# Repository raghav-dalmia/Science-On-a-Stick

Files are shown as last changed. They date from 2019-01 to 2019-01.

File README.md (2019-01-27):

# Science-On-a-Stick
Science on a Stick, as the name suggests, it is an experimental setup based on Python and Arduino, was developed to verify various laws of Physics such as Lenz's Law, Faraday's Law and Laws of Motion.

We have provided schematics of circuits and code for this project.

# Installation

## To install Arduino IDE
Click [here](https://www.arduino.cc/en/Main/Software) to download Arduino IDE.

## To setup up Python Environment
To download Python IDE, click [here](https://www.python.org/downloads/release/python-2715/).

**Note:-** t would be preferable to download the latest version Python2.7.

### To set up environment variables
----
**Windows 10 and Windows 8**

1. In Search, search for and then select: System (Control Panel)

2. Click the Advanced system settings link.

3. Click Environment Variables. In the section System Variables, find the PATH environment variable and select it. Click Edit. If the PATH environment variable does not exist, click New.

4. In the Edit System Variable (or New System Variable) window, specify the value (location of the folder where python installed) of the PATH environment variable. Click OK. Close all remaining windows by clicking OK.

5. Open Command prompt window, and run following command:
    
       python --version
       pip --version
       
 If pip is not installed in your laptop, refer [this.](https://github.com/pypa/get-pip)
## Install dependencies of python code
open Command prompt or terminal and run this command
    
    pip install pyserial
    pip install matplotlib
    pip install numpy

## To Install Eagle
Download Eagle (PCB design software) from this [link.](https://www.autodesk.in/products/eagle/free-download?referrer=%2Fproducts%2Feagle%2Ffree-download)

Open the given board layouts and fabricate them. The schematic folder has three schematics and their board layouts. 

**Images of Fabricated Board and coil**
---------------------------------------
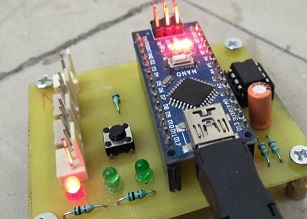
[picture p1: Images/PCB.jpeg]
main_board


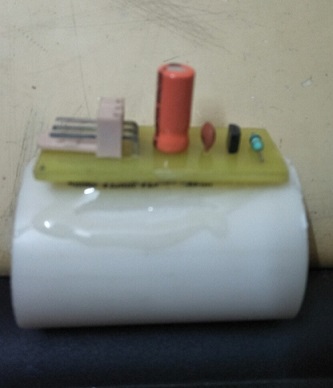
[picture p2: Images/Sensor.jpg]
sensor


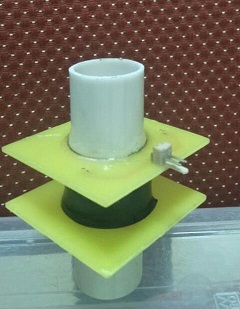
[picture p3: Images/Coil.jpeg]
coil


**!! More than 1000 turns (36 gauge copper wire) of coil winding can destroy the circuit**

# Usage

## Law's of MOtion

Set the experimental tube as shown in [picture.](https://github.com/raghav-dalmia/Science-On-a-Stick/blob/master/Images/Law's%20of%20Motion%20Setup.jpeg)

1. open Arduino IDE and upload `Laws_of_Motion` code.

2. For law's motion open the serial monitor and enter values asked by monitor.

**Output**
----------
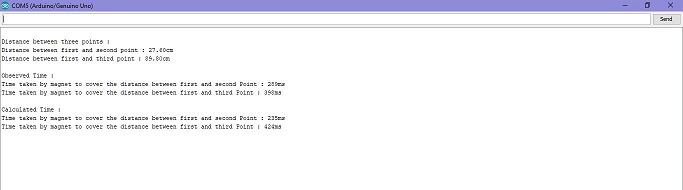
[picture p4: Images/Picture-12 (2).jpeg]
output


## Lenz's Law

Set the experimental setup as shown in [picture.](https://github.com/raghav-dalmia/Science-On-a-Stick/blob/master/Images/Lenz's%20Law%20Setup.jpeg)

1. Open Arduino IDE and upload `Lenz_s_Law_Arduino` code.
2. Open python code and change com port value(in Windows its `com5`, in Linux its `/dev/ttyUSB0`)
    
       arduinoData=serial.Serial('com5',115200)
3. Open Command prompt or terminal and  change current working directory to directory of this python code using
         
       cd <complete-path>
4. Run python code by the following command

       python "Lenz's_Law_Python.py"
   
**Output**
----------
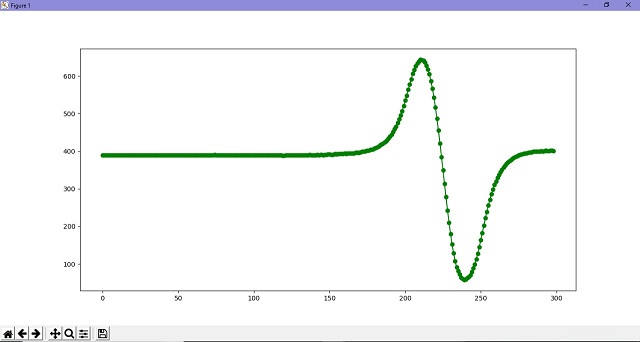
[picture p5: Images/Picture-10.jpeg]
output1


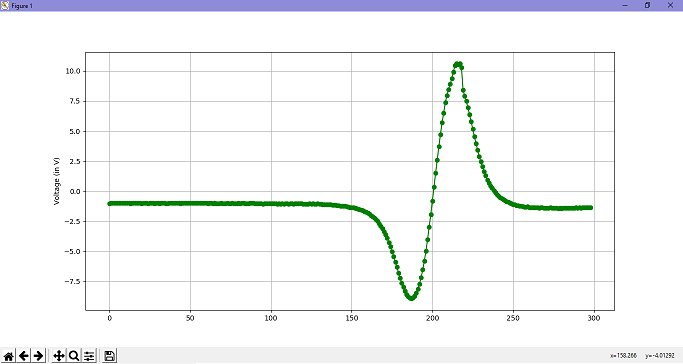
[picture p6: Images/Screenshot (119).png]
output2

       
# Credits
This experimental setup is developed under the guidance of Prof. D.V. Gadre, Director CEDT, NSUT.

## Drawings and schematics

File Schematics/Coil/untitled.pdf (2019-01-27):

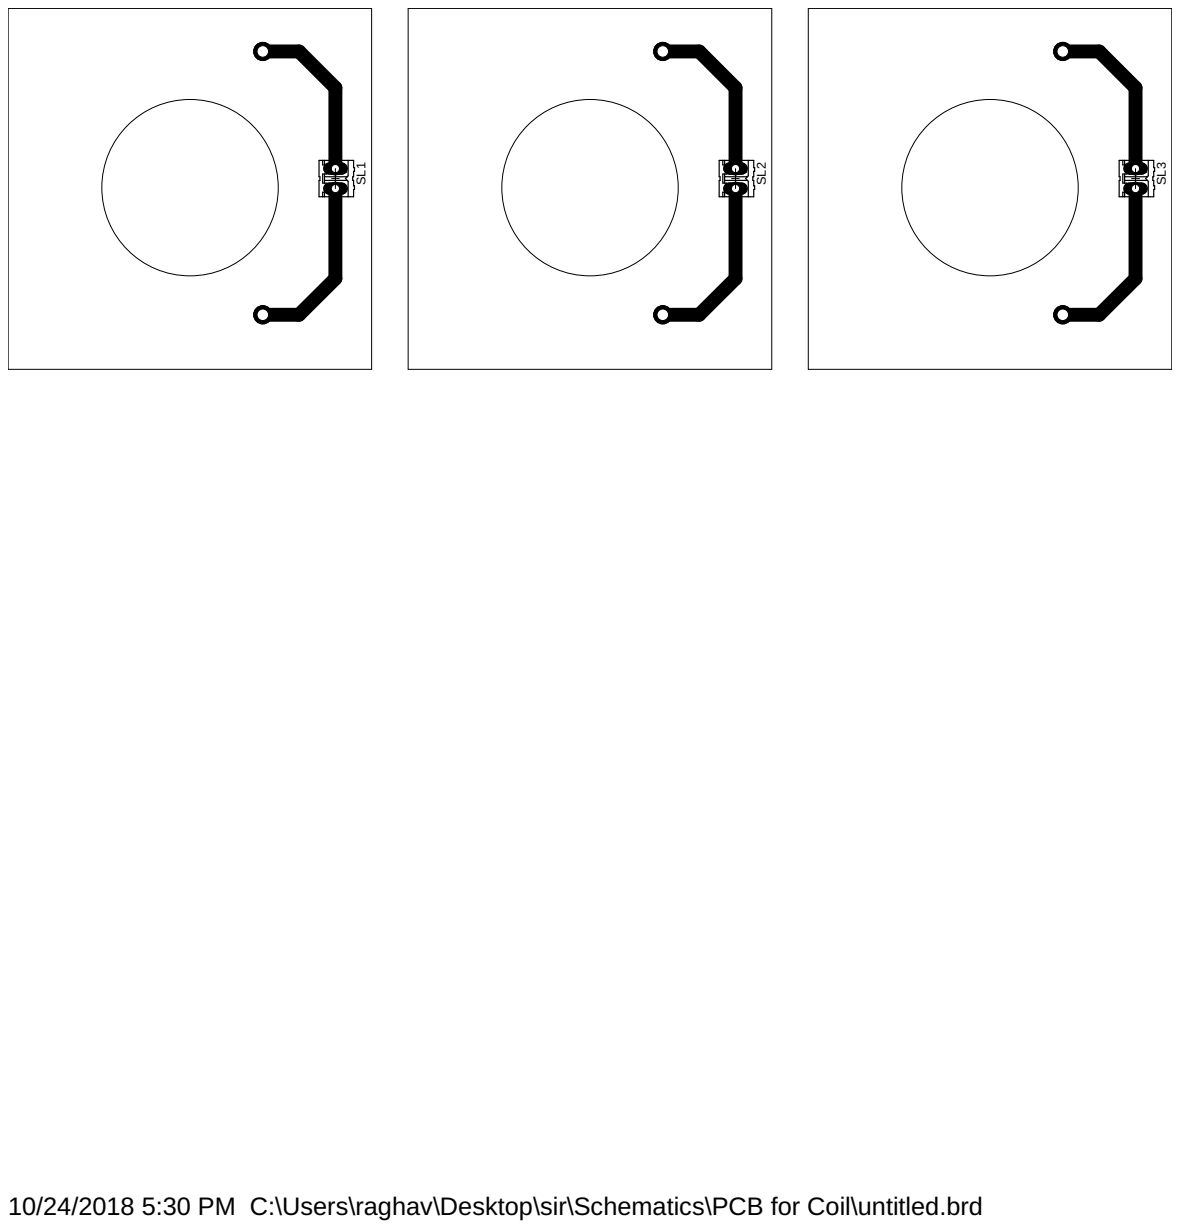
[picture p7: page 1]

10/24/2018 5:30 PM C:\Users\raghav\Desktop\sir\Schematics\PCB for Coil\untitled.brd

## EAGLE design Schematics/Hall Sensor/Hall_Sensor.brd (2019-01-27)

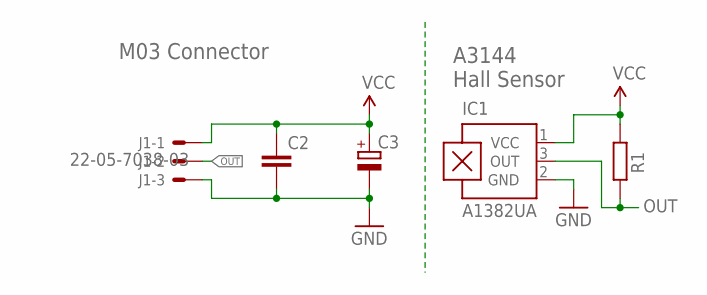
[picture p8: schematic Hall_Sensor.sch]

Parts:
C2: C-EU025-025X050; C025-025X050
C3: CPOL-EUE2,5-6E; E2,5-6E
IC1: A1382UA; SIP3-UA
J1: 22-05-7038-03; 7395-03
R1: R-EU_0207/7; 0207/7

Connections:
GND: C2.2, C3.-, IC1.2 (GND), J1.3
OUT: IC1.3 (OUT), J1.2, R1.1
VCC: C2.1, C3.+, IC1.1 (VCC), J1.1, R1.2

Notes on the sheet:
M03 Connector
A3144 Hall Sensor

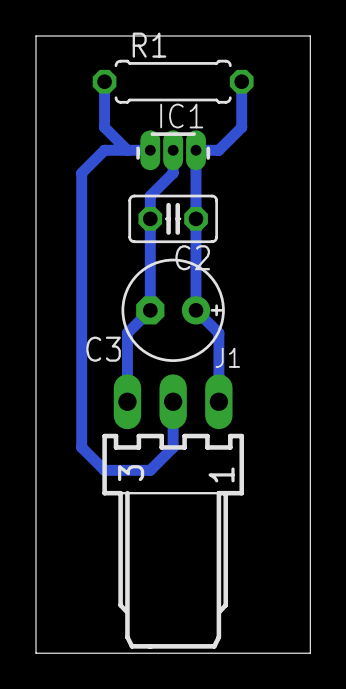
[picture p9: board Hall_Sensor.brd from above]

Board: 2 copper layers, 15.2 x 34.3 mm, 5 parts (0 on the bottom side), 3 nets.

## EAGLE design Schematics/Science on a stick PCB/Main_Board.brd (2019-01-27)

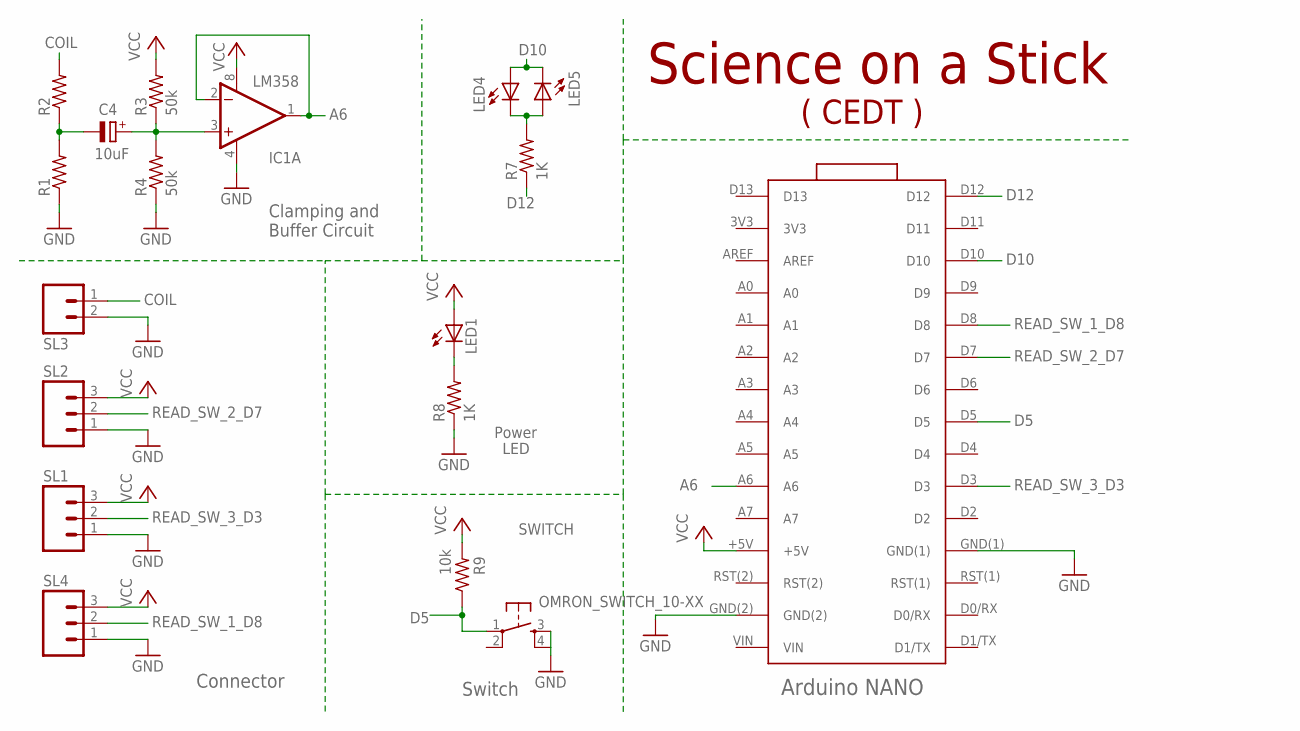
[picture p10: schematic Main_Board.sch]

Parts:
C4: 10uF; E2,5-5
IC1: LM358; DIP08
LED1, LED4, LED5: LED3MM
R1, R2: RESISTOR0207/7; 0207/7
R3, R4: 50k; 0207/7
R7, R8: 1K; 0207/7
R9: 10k; 0207/7
SL1, SL2, SL4: M03; 03P
SL3: M02; 02P
SWITCH: OMRON_SWITCH_10-XX; B3F-10XX
U$1: ARDUINO_NANO_3_ARDUINO(NANO_3.0); ARDUINO_NANO_3_ARDUINO_NANO_30PIN

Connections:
A6: IC1.1 (OUT), IC1.2 (-IN), U$1.A6
CLAMP_SIGNAL: C4.+, IC1.3 (+IN), R3.1, R4.2
COIL: R2.2, SL3.1
D5: R9.1, SWITCH.1, U$1.D5
D10: LED4.A, LED5.K (C), U$1.D10
D12: R7.1, U$1.D12
GND: IC1.4 (V-), R1.1, R4.1, R8.1, SL1.1, SL2.1, SL3.2, SL4.1, SWITCH.3 (S), SWITCH.4 (S1), U$1.GND(1), U$1.GND(2)
unnamed: C4.-, R1.2, R2.1
unnamed: LED1.K (C), R8.2
unnamed: LED4.K (C), LED5.A, R7.2
READ_SW_1_D8: SL4.2, U$1.D8
READ_SW_2_D7: SL2.2, U$1.D7
READ_SW_3_D3: SL1.2, U$1.D3
VCC: IC1.8 (V+), LED1.A, R3.2, R9.2, SL1.3, SL2.3, SL4.3, U$1.+5V

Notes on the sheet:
Arduino NANO
Science on a Stick
( CEDT )
Power
LED
Switch
Connector
Clamping and Buffer Circuit

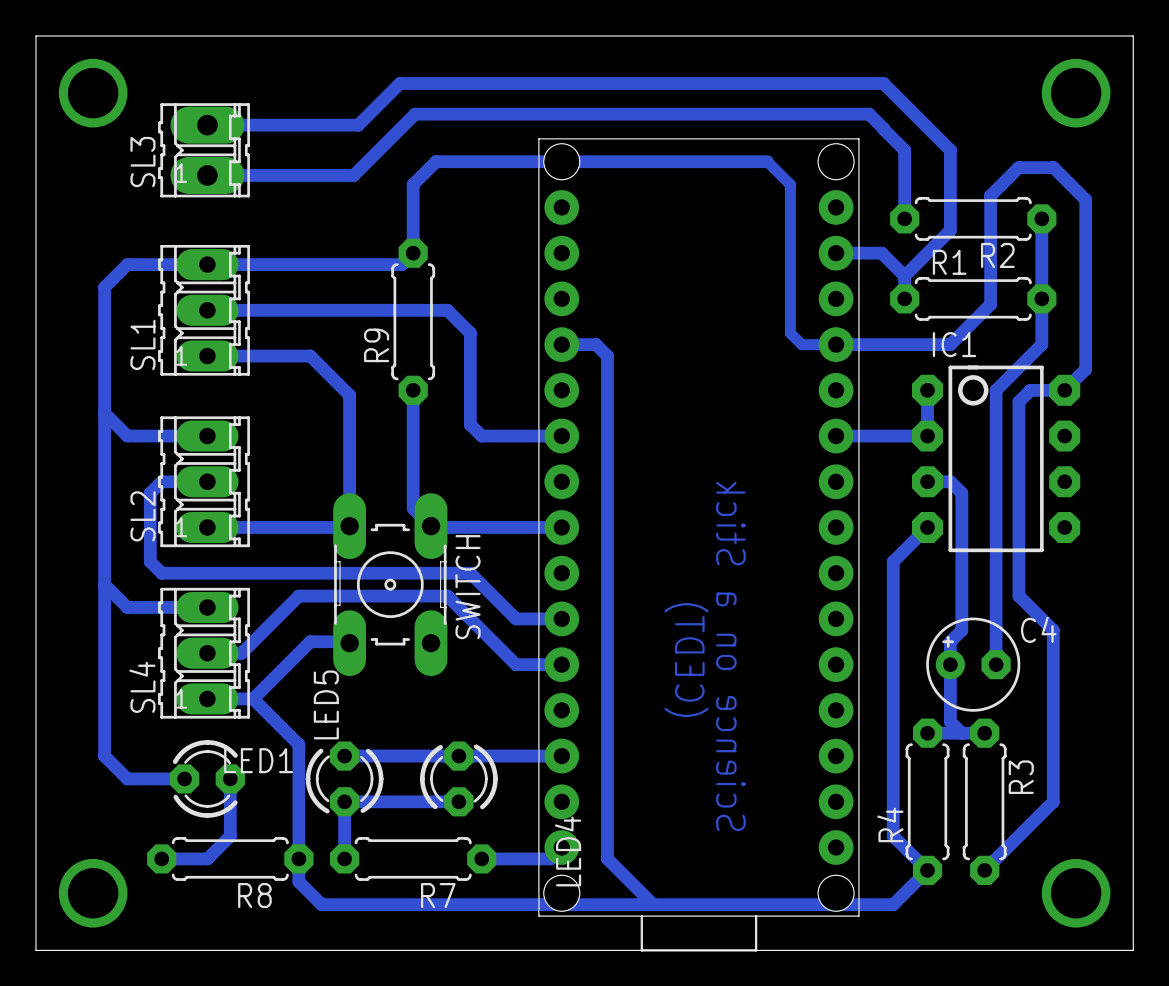
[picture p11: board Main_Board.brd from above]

Board: 2 copper layers, 61.0 x 50.8 mm, 18 parts (0 on the bottom side), 14 nets.

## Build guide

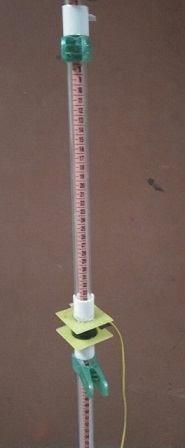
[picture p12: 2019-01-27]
Images/Lenz's Law Setup.jpeg

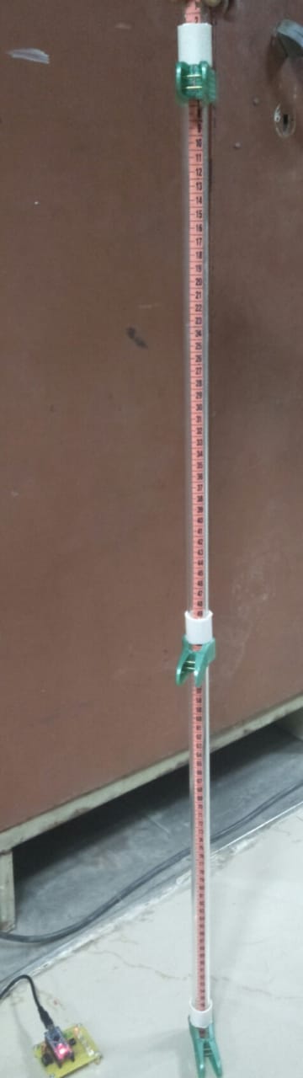
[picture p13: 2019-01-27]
Images/Law's of Motion Setup.jpeg

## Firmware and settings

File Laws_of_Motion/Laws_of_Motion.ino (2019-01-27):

// define pins used
#define hallSensor1 8
#define hallSensor2 7
#define hallSensor3 3
#define led_vcc 10
#define led_gnd 12

long int timet[3];   //buffer to store time of interaction
void setup() 
{
Serial.begin(9600);           // set baud rate to 9600
// initialize pins
pinMode(hallSensor1,INPUT);
pinMode(hallSensor2,INPUT);
pinMode(hallSensor3,INPUT);
pinMode(led_vcc,OUTPUT);
pinMode(led_gnd,OUTPUT);
digitalWrite(led_vcc,HIGH);
digitalWrite(led_gnd,LOW);
}

void loop()
{
// read height between the hall sensors
int cnt=0;
int h[2];
bool p=true;
while(cnt!=2)
{
  if(p && cnt<2)
  {
    if(cnt==0)
    {
      Serial.print("Enter distance between first and second point in cm : ");
      p=false;
    }
    else if(cnt==1)
    {
      Serial.print("Enter distance between first and third point in cm : ");
      p=false;
    }
  }
  int a;
  a=Serial.parseInt();
  if(a!=0)
  {
    h[cnt]=a;
    Serial.print(h[cnt]);
    Serial.println("cm");
    cnt++;
    p=true;
  }
}
// read time of interaction
Serial.println();
Serial.println("Now drop the magnet....");
while (true)
{
  if(digitalRead(hallSensor1)==HIGH)  // trigger when magnet interact with first sensor
  {
    //Serial.println(1);
    timet[0]=millis();
    break;
  }
}
while (true)
{
  if(digitalRead(hallSensor2)==HIGH)  // trigger when magnet interact with second sensor
  {
    //Serial.println(2);
    timet[1]=millis();
    break;
  }
}
while (true)
{
  if(digitalRead(hallSensor3)==HIGH)  // trigger when magnet interact with third sensor
  {
    //Serial.println(3);
    timet[2]=millis();
    break;
  }
}
// print time take
Serial.println("Observed Time : ");
Serial.println();
Serial.print("Time taken by object to cross second point is : ");
Serial.print(timet[1]-timet[0]);
Serial.println(" ms");
Serial.print("Time taken by object to cross third point is : ");
Serial.print(timet[2]-timet[0]);
Serial.println(" ms");
Serial.println();
// calculation of acceleration due to gravity
Serial.print("Calculated acceleration due to gravity is : ");
float g[2];
g[0]=0.02*h[0];
float t=timet[1]-timet[0];
t/=1000;
g[0]/=t;
g[0]/=t;
g[1]=0.02*h[1];
t=timet[2]-timet[0];
t/=1000;
g[1]/=t;
g[1]/=t;
float G=g[0]+g[1];
G/=2;
Serial.print(G);
Serial.println(" m/s^2");
}

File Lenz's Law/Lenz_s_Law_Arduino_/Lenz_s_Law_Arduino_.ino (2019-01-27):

// define pin numbers
#define analogPin A6
#define hallSensor1 8
#define hallSensor2 3
#define led_vcc 12
#define led_gnd 10

long int t;

void setup() {
  Serial.begin(115200);       // set baud rate to 115200
  // initialize pins and their mode of operation
  pinMode(analogPin,INPUT);   
  pinMode(hallSensor1,INPUT);
  pinMode(hallSensor2,INPUT);
  pinMode(led_vcc,OUTPUT);
  pinMode(led_gnd,OUTPUT);
  digitalWrite(led_vcc,HIGH);
  digitalWrite(led_gnd,LOW);
}
 
void loop() {
  while(true){
  if(digitalRead(hallSensor1)==HIGH){  // trigger when magnet reaches to first sensor
    t=millis();                        // save time of interaction
    break;
  }}
  while(true){
    if(digitalRead(hallSensor2)==HIGH) // trigger when magnet reaches to second sensor
      {
        for(int i=0;i<30;i++)
          Serial.println(analogRead(analogPin));
        Serial.println("3000");       // send code(3000) to indicate "stop reading analog values"  
        Serial.println(t);            // send time of first interaction
        Serial.println(millis());     // send time of second interaction
        break;    
      }
      else
      {
        Serial.println(analogRead(analogPin)); // send analog values
      }
}
}

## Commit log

2019-01-27 Board Layouts and Schematics
    [Coil.sch, Hall_Sensor.brd, Hall_Sensor.sch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]
2019-01-27 circuit of Magnetic Sensor

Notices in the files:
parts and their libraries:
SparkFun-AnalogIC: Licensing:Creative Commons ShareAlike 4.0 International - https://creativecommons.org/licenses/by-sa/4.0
